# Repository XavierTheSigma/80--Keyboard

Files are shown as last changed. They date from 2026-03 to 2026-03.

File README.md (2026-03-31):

# Keyboard
My Keyboard is a standard 80% keyboard with an added Rotary Encoder for volume control.

I made this Keyboard for myself, And to learn. This was my first time using Chip on Board tech, so it was quite a challenge for me, but it helped me learn alot.

## Features:
- 80% Keyboard
- 87 Keys
- Rotary Encoder 
- Arrow Keys
- F Keys
- Chip On Board

## CAD Model:
I designed the Case to fit together with 3 pieces and 8 M2.5 screws. The 3 pieces are the Bottom of the case, The sides of the case (with a cutout for the USB-C) and the Top of the case, which includes the switch plate and the Top Frame. The Bottom and Sides are clearance holes and the screw threads into the top. The screw threads into 1.4mm of the top part and the screws are actually held .5mm higher than the bottom instead of flush.

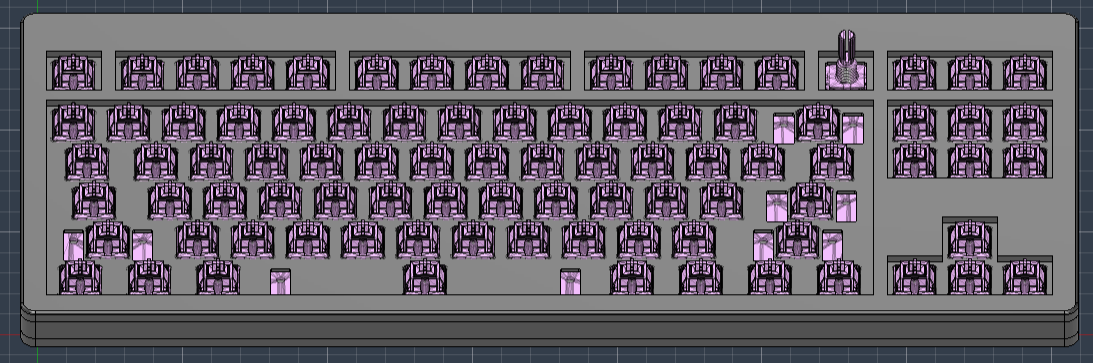
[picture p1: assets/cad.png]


## PCB:
I made my PCB in KiCad. This was my first time using CoB, Chip on Board, where instead of using a microcontroller, The RP2040 chip is directly on the board with all the other necessary components. I ended up reffereing to [RP2040 Datasheet](https://pip.raspberrypi.com/documents/RP-008371-DS-rp2040-datasheet.pdf) alot for this. 

Here is the Schematic, I spend alot of time figuring out how to get the whole CoB system working, but I think I did well.

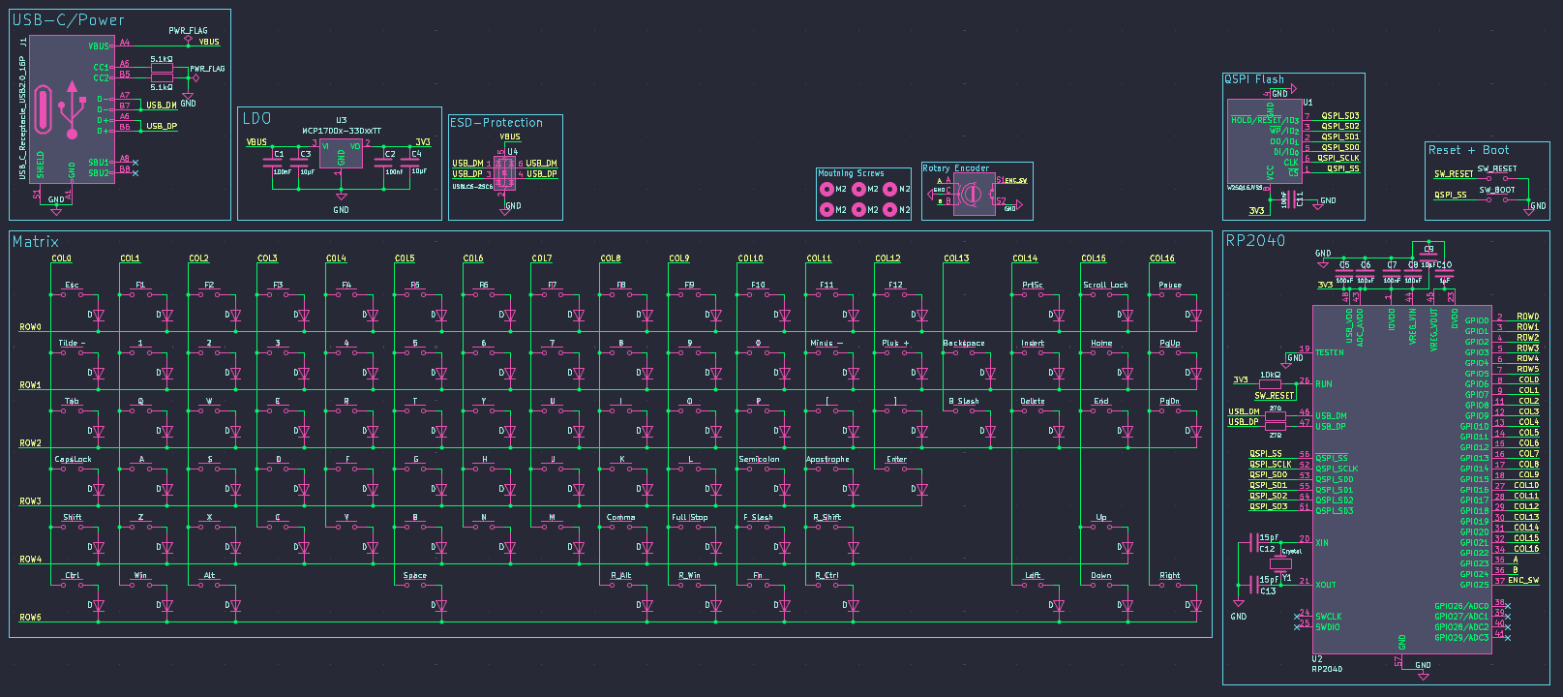
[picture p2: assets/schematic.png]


Here is the PCB, I think I was able to make it pretty Compact with the components, however I am still unsure about the USB-C port.

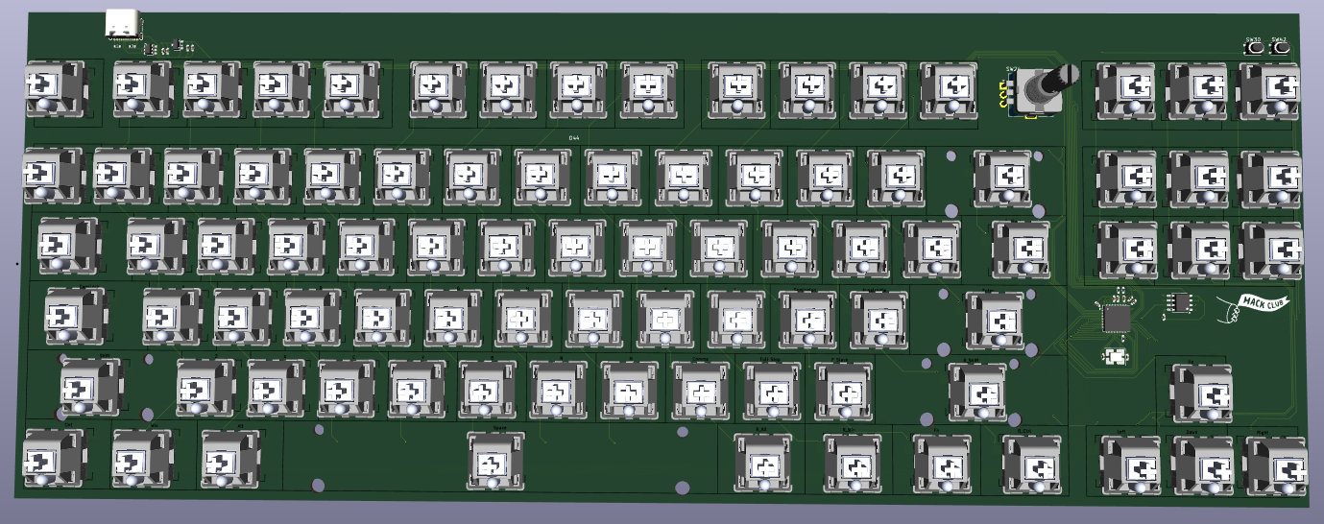
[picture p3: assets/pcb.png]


## Firmware:
I decided on [KMK](https://github.com/KMKfw/kmk_firmware) firmware for this keyboard, as it is quite easy to code and implement.

## BOM:
|Name |Purpose |Quantity|Total Cost (USD)|Link |Distributor|
|---|---|---|---|---|---|
|M2.5x12mm Screws |Hold the Case Together |100 |4.29 |https://www.aliexpress.com/item/1005006149650871.html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|Aliexpress |
|PCBA |Printed Circuit Board |2 |53.90 |https://cart.jlcpcb.com/shopcart/cart |JLCPCB |
|3x4mm SMD tactile switch|BOOT and RESET |100 |3.04 |https://www.aliexpress.com/item/1005005551946922.html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 |Aliexpress |
|Hotswap Sockets |For the switches to go into.|110 |6.78 |https://www.aliexpress.com/item/1005007232040760.html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 |Aliexpress |
|Rotary Encoder |Volume Control |2 |2.33 |https://www.aliexpress.com/item/1005009360298765.html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 |Aliexpress |
|Mechanical Switches |Register Keystrokes |90 |11.10 |https://www.aliexpress.com/item/1005010733013518.html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 |Aliexpress |
|Keycap Set |To press on |1 |12.61 |https://www.aliexpress.com/item/1005009316481772.html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 |Aliexpress |
|Stabilizers |Prevent Wobbling |1 |2.60 |https://www.aliexpress.com/item/1005007212869086.html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 |Aliexpress |
|1N5819 Diode (SMD) |Diodes for Matrix |100 |2.03 |https://www.aliexpress.com/item/1005010391501956.html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 |Aliexpress |
| | | | | | |

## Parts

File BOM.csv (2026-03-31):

Name | Purpose | Quantity | Total Cost (USD) | Link | Distributor
M2.5x12mm Screws | Hold the Case Together | 100 | 4.29 | https://www.aliexpress.com/item/1005006149650871.html?curPageLogUid=wg6dSTH9tu8G | Aliexpress
PCBA | Printed Circuit Board | 2 | 53.90 | https://cart.jlcpcb.com/shopcart/cart | JLCPCB
3x4mm SMD tactile switch | BOOT and RESET | 100 | 3.04 | https://www.aliexpress.com/item/1005005551946922.html?mp=1 | Aliexpress
Hotswap Sockets | For the switches to go into. | 110 | 6.78 | https://www.aliexpress.com/item/1005007232040760.html?mp=1 | Aliexpress
Rotary Encoder | Volume Control | 2 | 2.33 | https://www.aliexpress.com/item/1005009360298765.html?mp=1 | Aliexpress
Mechanical Switches | Register Keystrokes | 90 | 11.10 | https://www.aliexpress.com/item/1005010733013518.html?mp=1 | Aliexpress
Keycap Set | To press on | 1 | 12.61 | https://www.aliexpress.com/item/1005009316481772.html?mp=1 | Aliexpress
Stabilizers | Prevent Wobbling | 1 | 2.60 | https://www.aliexpress.com/item/1005007212869086.html?mp=1 | Aliexpress
1N5819 Diode (SMD) | Diodes for Matrix | 100 | 2.03 | https://www.aliexpress.com/item/1005010391501956.html?mp=1 | Aliexpress

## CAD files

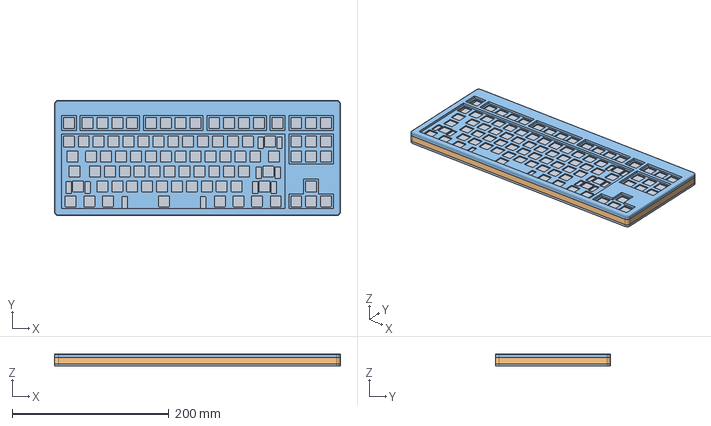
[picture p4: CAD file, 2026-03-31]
CAD/Keyboard.step
365.4 x 147.4 x 15.6 mm

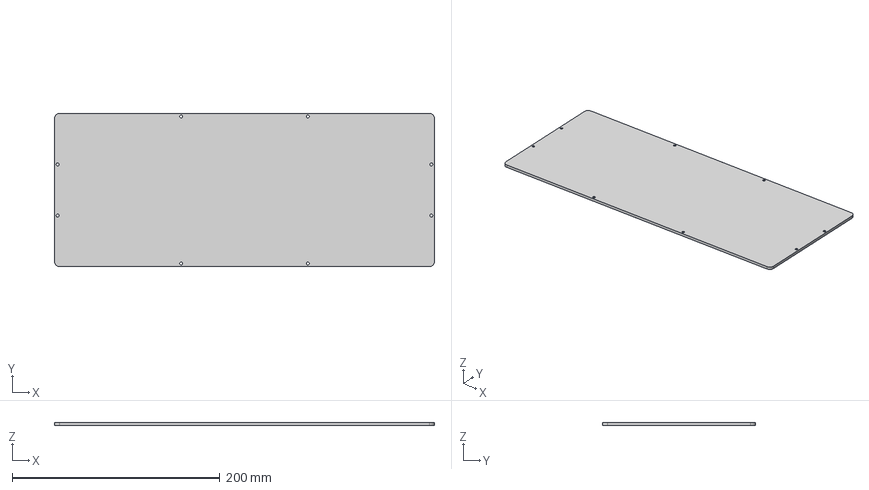
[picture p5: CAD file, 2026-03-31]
production/Bottom.step
365.4 x 147.4 x 3.00 mm

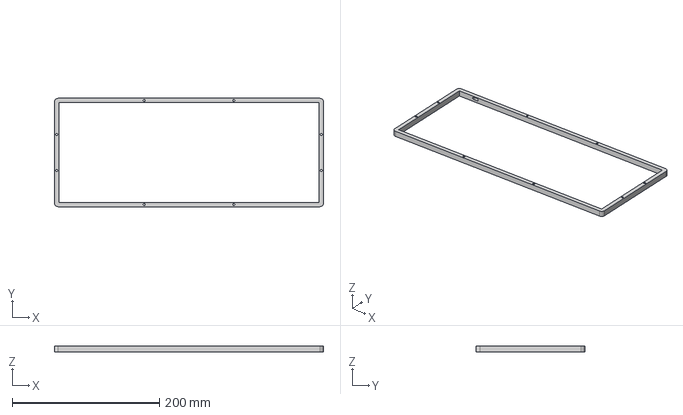
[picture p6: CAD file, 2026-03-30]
production/Sides.step
365.4 x 147.4 x 8.10 mm

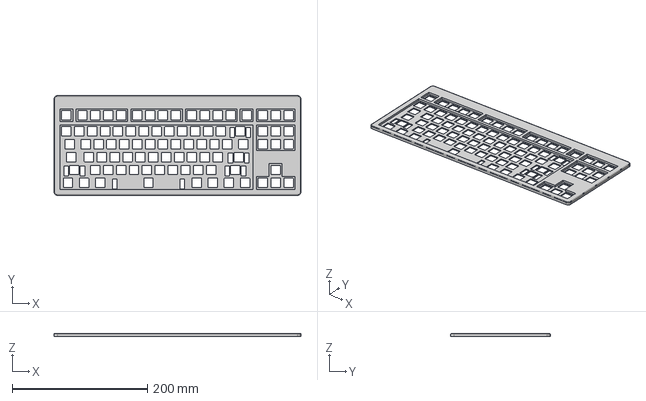
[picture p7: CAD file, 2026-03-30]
production/Top.step
365.4 x 147.4 x 4.50 mm

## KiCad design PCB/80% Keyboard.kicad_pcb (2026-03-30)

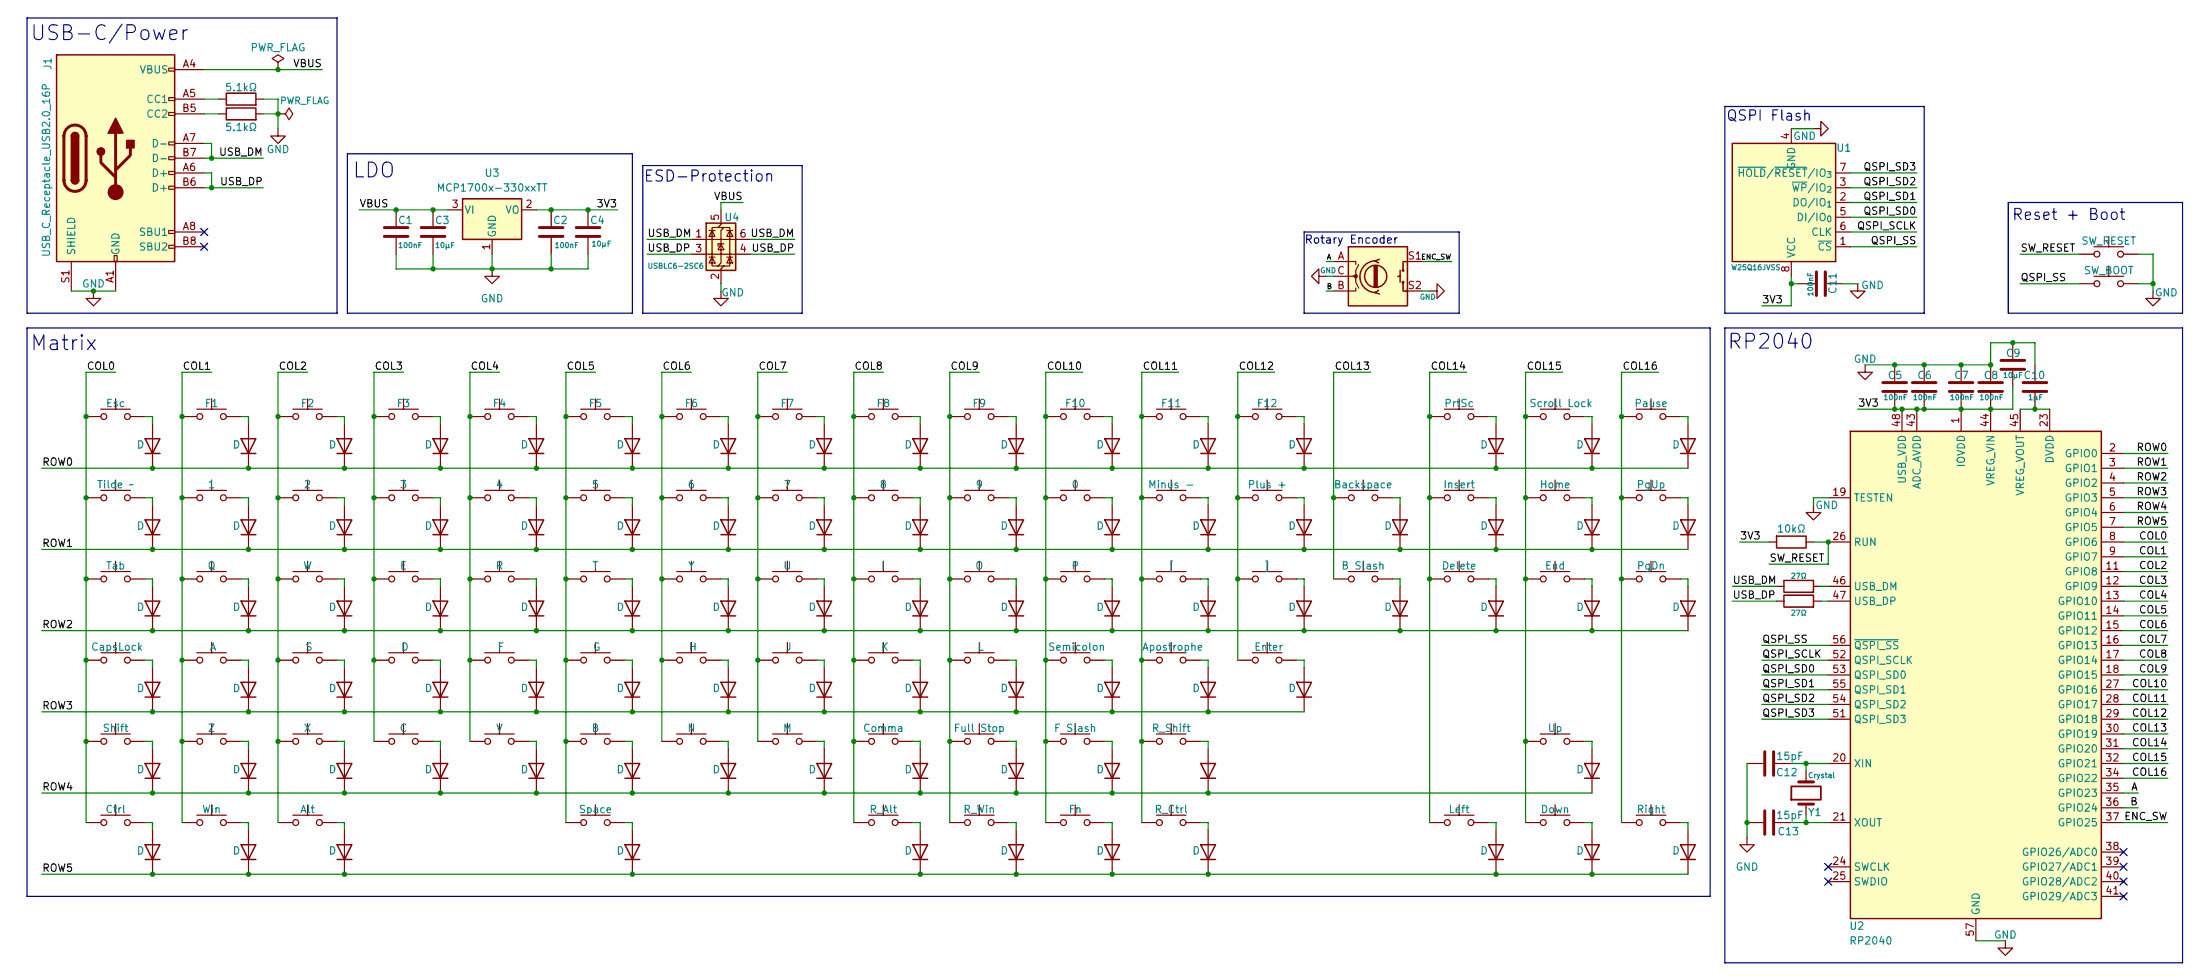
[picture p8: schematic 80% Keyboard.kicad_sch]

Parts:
C1, C2, C5, C6, C7, C8, C11: 100nF; C_0402_1005Metric_Pad0.74x0.62mm_HandSolder
C3, C4, C9: 10µF; C_0402_1005Metric_Pad0.74x0.62mm_HandSolder
C10: 1µF; C_0402_1005Metric_Pad0.74x0.62mm_HandSolder
C12, C13: 15pF; C_0402_1005Metric_Pad0.74x0.62mm_HandSolder
D1, D2, D3, D4, D5, D6, D7, D8, D9, D10, D11, D12, D13, D14, D15, D16, D17, D18, D19, D20, D21, D22, D23, D25, D26, D27, D28, D29, D31, D32, D33, D34, D35, D36, D37, D38, D39, D40, D41, D43, D44, D45, D46, D47, D49, D50, D51, D52, D53, D54, D55, D56, D57, D58, D59, D60, D61, D62, D63, D64, D65, D66, D67, D68, D69, D70, D71, D72, D73, D74, D75, D76, D80, D81, D85, D86, D87, D90, D91, D92, D93, D95, D96, D97, D98, D99, D102: D; D_SOD-123
J1: USB_C_Receptacle_USB2.0_16P; USB_C_Receptacle_GCT_USB4105-xx-A_16P_TopMnt_Horizontal
R1, R2: 5.1kΩ; R_0402_1005Metric_Pad0.72x0.64mm_HandSolder
R3: 10kΩ; R_0402_1005Metric_Pad0.72x0.64mm_HandSolder
R4, R5: 27Ω; R_0402_1005Metric_Pad0.72x0.64mm_HandSolder
SW1: Esc; MX-Hotswap-1U
SW2: Tilde ~; MX-Hotswap-1U
SW3: Tab; MX-Hotswap-1.5U
SW4: CapsLock; MX-Hotswap-1.75U
SW5: Shift; MX-Hotswap-2.25U
SW6: Ctrl; MX-Hotswap-1.25U
SW7: F1; MX-Hotswap-1U
SW8: 1; MX-Hotswap-1U
SW9: Q; MX-Hotswap-1U
SW10: A; MX-Hotswap-1U
SW11: Z; MX-Hotswap-1U
SW12: Win; MX-Hotswap-1.25U
SW13: F2; MX-Hotswap-1U
SW14: 2; MX-Hotswap-1U
SW15: W; MX-Hotswap-1U
SW16: S; MX-Hotswap-1U
SW17: X; MX-Hotswap-1U
SW18: Alt; MX-Hotswap-1.25U
SW19: F3; MX-Hotswap-1U
SW20: 3; MX-Hotswap-1U
SW21: E; MX-Hotswap-1U
SW22: D; MX-Hotswap-1U
SW23: C; MX-Hotswap-1U
SW24: RotaryEncoder; RotaryEncoder_Alps_EC11E-Switch_Vertical_H20mm
SW25: F4; MX-Hotswap-1U
SW26: 4; MX-Hotswap-1U
SW27: R; MX-Hotswap-1U
SW28: F; MX-Hotswap-1U
SW29: V; MX-Hotswap-1U
SW30: SW_BOOT; SW_Push_1P1T_NO_Vertical_Wuerth_434133025816
SW31: F5; MX-Hotswap-1U
SW32: 5; MX-Hotswap-1U
SW33: T; MX-Hotswap-1U
SW34: G; MX-Hotswap-1U
SW35: B; MX-Hotswap-1U
SW36: Space; MX-Hotswap-6.25U
SW37: F6; MX-Hotswap-1U
SW38: 6; MX-Hotswap-1U
SW39: Y; MX-Hotswap-1U
SW40: H; MX-Hotswap-1U
SW41: N; MX-Hotswap-1U
SW42: SW_RESET; SW_Push_1P1T_NO_Vertical_Wuerth_434133025816
SW43: F7; MX-Hotswap-1U
SW44: 7; MX-Hotswap-1U
SW45: U; MX-Hotswap-1U
SW46: J; MX-Hotswap-1U
SW47: M; MX-Hotswap-1U
SW49: F8; MX-Hotswap-1U
SW50: 8; MX-Hotswap-1U
SW51: I; MX-Hotswap-1U
SW52: K; MX-Hotswap-1U
SW53: Comma; MX-Hotswap-1U
SW54: R_Alt; MX-Hotswap-1.25U
SW55: F9; MX-Hotswap-1U
SW56: 9; MX-Hotswap-1U
SW57: O; MX-Hotswap-1U
SW58: L; MX-Hotswap-1U
SW59: Full Stop; MX-Hotswap-1U
SW60: R_Win; MX-Hotswap-1.25U
SW61: F10; MX-Hotswap-1U
SW62: 0; MX-Hotswap-1U
SW63: P; MX-Hotswap-1U
SW64: Semicolon; MX-Hotswap-1U
SW65: F Slash; MX-Hotswap-1U
SW66: Fn; MX-Hotswap-1.25U
SW67: F11; MX-Hotswap-1U
SW68: Minus -; MX-Hotswap-1U
SW69: [; MX-Hotswap-1U
SW70: Apostrophe; MX-Hotswap-1U
SW71: R_Shift; MX-Hotswap-2.75U
SW72: R_Ctrl; MX-Hotswap-1.25U
SW73: F12; MX-Hotswap-1U
SW74: Plus +; MX-Hotswap-1U
SW75: ]; MX-Hotswap-1U
SW76: Enter; MX-Hotswap-2.25U
SW80: Backspace; MX-Hotswap-2U
SW81: B Slash; MX-Hotswap-1.5U
SW85: PrtSc; MX-Hotswap-1U
SW86: Insert; MX-Hotswap-1U
SW87: Delete; MX-Hotswap-1U
SW90: Left; MX-Hotswap-1U
SW91: Scroll Lock; MX-Hotswap-1U
SW92: Home; MX-Hotswap-1U
SW93: End; MX-Hotswap-1U
SW95: Up; MX-Hotswap-1U
SW96: Down; MX-Hotswap-1U
SW97: Pause; MX-Hotswap-1U
SW98: PgUp; MX-Hotswap-1U
SW99: PgDn; MX-Hotswap-1U
SW102: Right; MX-Hotswap-1U
U1: W25Q16JVSS; SOIC-8_3.9x4.9mm_P1.27mm
U2: RP2040; QFN-56-1EP_7x7mm_P0.4mm_EP3.2x3.2mm
U3: MCP1700x-330xxTT; SOT-23
U4: USBLC6-2SC6; SOT-23-6
Y1: Crystal; Crystal_SMD_3225-4Pin_3.2x2.5mm_HandSoldering

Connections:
/3V3: C2.1, C4.1, C5.2, C6.2, C7.2, C8.2, C9.2, C11.2, R3.2, U1.8 (VCC), U2.1 (IOVDD), U2.10 (IOVDD), U2.22 (IOVDD), U2.33 (IOVDD), U2.42 (IOVDD), U2.43 (ADC_AVDD), U2.44 (VREG_VIN), U2.48 (USB_VDD), U2.49 (IOVDD), U3.2 (VO)
/A: SW24.A, U2.35 (GPIO23)
/B: SW24.B, U2.36 (GPIO24)
/COL0: SW1.1, SW2.1, SW3.1, SW4.1, SW5.1, SW6.1, U2.8 (GPIO6)
/COL1: SW7.1, SW8.1, SW9.1, SW10.1, SW11.1, SW12.1, U2.9 (GPIO7)
/COL2: SW13.1, SW14.1, SW15.1, SW16.1, SW17.1, SW18.1, U2.11 (GPIO8)
/COL3: SW19.1, SW20.1, SW21.1, SW22.1, SW23.1, U2.12 (GPIO9)
/COL4: SW25.1, SW26.1, SW27.1, SW28.1, SW29.1, U2.13 (GPIO10)
/COL5: SW31.1, SW32.1, SW33.1, SW34.1, SW35.1, SW36.1, U2.14 (GPIO11)
/COL6: SW37.1, SW38.1, SW39.1, SW40.1, SW41.1, U2.15 (GPIO12)
/COL7: SW43.1, SW44.1, SW45.1, SW46.1, SW47.1, U2.16 (GPIO13)
/COL8: SW49.1, SW50.1, SW51.1, SW52.1, SW53.1, SW54.1, U2.17 (GPIO14)
/COL9: SW55.1, SW56.1, SW57.1, SW58.1, SW59.1, SW60.1, U2.18 (GPIO15)
/COL10: SW61.1, SW62.1, SW63.1, SW64.1, SW65.1, SW66.1, U2.27 (GPIO16)
/COL11: SW67.1, SW68.1, SW69.1, SW70.1, SW71.1, SW72.1, U2.28 (GPIO17)
/COL12: SW73.1, SW74.1, SW75.1, SW76.1, U2.29 (GPIO18)
/COL13: SW80.1, SW81.1, U2.30 (GPIO19)
/COL14: SW85.1, SW86.1, SW87.1, SW90.1, U2.31 (GPIO20)
/COL15: SW91.1, SW92.1, SW93.1, SW95.1, SW96.1, U2.32 (GPIO21)
/COL16: SW97.1, SW98.1, SW99.1, SW102.1, U2.34 (GPIO22)
/ENC_SW: SW24.S1, U2.37 (GPIO25)
/QSPI_SCLK: U1.6 (CLK), U2.52 (QSPI_SCLK)
/QSPI_SD0: U1.5 (DI/IO_{0}), U2.53 (QSPI_SD0)
/QSPI_SD1: U1.2 (DO/IO_{1}), U2.55 (QSPI_SD1)
/QSPI_SD2: U1.3 (~WP/IO_{2}), U2.54 (QSPI_SD2)
/QSPI_SD3: U1.7 (~HOLD/~RESET/IO_{3}), U2.51 (QSPI_SD3)
/QSPI_SS: SW30.1, U1.1 (~CS), U2.56 (~QSPI_SS)
/ROW0: D1.1 (K), D7.1 (K), D13.1 (K), D19.1 (K), D25.1 (K), D31.1 (K), D37.1 (K), D43.1 (K), D49.1 (K), D55.1 (K), D61.1 (K), D67.1 (K), D73.1 (K), D85.1 (K), D91.1 (K), D97.1 (K), U2.2 (GPIO0)
/ROW1: D2.1 (K), D8.1 (K), D14.1 (K), D20.1 (K), D26.1 (K), D32.1 (K), D38.1 (K), D44.1 (K), D50.1 (K), D56.1 (K), D62.1 (K), D68.1 (K), D74.1 (K), D80.1 (K), D86.1 (K), D92.1 (K), D98.1 (K), U2.3 (GPIO1)
/ROW2: D3.1 (K), D9.1 (K), D15.1 (K), D21.1 (K), D27.1 (K), D33.1 (K), D39.1 (K), D45.1 (K), D51.1 (K), D57.1 (K), D63.1 (K), D69.1 (K), D75.1 (K), D81.1 (K), D87.1 (K), D93.1 (K), D99.1 (K), U2.4 (GPIO2)
/ROW3: D4.1 (K), D10.1 (K), D16.1 (K), D22.1 (K), D28.1 (K), D34.1 (K), D40.1 (K), D46.1 (K), D52.1 (K), D58.1 (K), D64.1 (K), D70.1 (K), D76.1 (K), U2.5 (GPIO3)
/ROW4: D5.1 (K), D11.1 (K), D17.1 (K), D23.1 (K), D29.1 (K), D35.1 (K), D41.1 (K), D47.1 (K), D53.1 (K), D59.1 (K), D65.1 (K), D71.1 (K), D95.1 (K), U2.6 (GPIO4)
/ROW5: D6.1 (K), D12.1 (K), D18.1 (K), D36.1 (K), D54.1 (K), D60.1 (K), D66.1 (K), D72.1 (K), D90.1 (K), D96.1 (K), D102.1 (K), U2.7 (GPIO5)
/SW_RESET: R3.1, SW42.1, U2.26 (RUN)
/USB_DM: J1.A7 (D-), J1.B7 (D-), R4.1, U4.1 (I/O1), U4.6 (I/O1)
/USB_DP: J1.A6 (D+), J1.B6 (D+), R5.1, U4.3 (I/O2), U4.4 (I/O2)
/VBUS: C1.1, C3.1, J1.A4 (VBUS), J1.A9 (VBUS), J1.B4 (VBUS), J1.B9 (VBUS), U3.3 (VI), U4.5 (VBUS)
GND: C1.2, C2.2, C3.2, C4.2, C5.1, C6.1, C7.1, C8.1, C9.1, C10.1, C11.1, C12.1, C13.1, J1.A1 (GND), J1.A12 (GND), J1.B1 (GND), J1.B12 (GND), J1.S1 (SHIELD), R1.2, R2.2, SW24.C, SW24.S2, SW30.2, SW42.2, U1.4 (GND), U2.19 (TESTEN), U2.57 (GND), U3.1 (GND), U4.2 (GND), Y1.3, Y1.4
unnamed: D1.2 (A), SW1.2
unnamed: D2.2 (A), SW2.2
unnamed: D3.2 (A), SW3.2
unnamed: D4.2 (A), SW4.2
unnamed: D5.2 (A), SW5.2
unnamed: D6.2 (A), SW6.2
unnamed: D7.2 (A), SW7.2
unnamed: D8.2 (A), SW8.2
unnamed: D9.2 (A), SW9.2
unnamed: D10.2 (A), SW10.2
unnamed: D11.2 (A), SW11.2
unnamed: D12.2 (A), SW12.2
unnamed: D13.2 (A), SW13.2
unnamed: D14.2 (A), SW14.2
unnamed: D15.2 (A), SW15.2
unnamed: D16.2 (A), SW16.2
unnamed: D17.2 (A), SW17.2
unnamed: D18.2 (A), SW18.2
unnamed: D19.2 (A), SW19.2
unnamed: D20.2 (A), SW20.2
unnamed: D21.2 (A), SW21.2
unnamed: D22.2 (A), SW22.2
unnamed: D23.2 (A), SW23.2
unnamed: D25.2 (A), SW25.2
unnamed: D26.2 (A), SW26.2
unnamed: D27.2 (A), SW27.2
unnamed: D28.2 (A), SW28.2
unnamed: D29.2 (A), SW29.2
unnamed: D31.2 (A), SW31.2
unnamed: D32.2 (A), SW32.2
unnamed: D33.2 (A), SW33.2
unnamed: D34.2 (A), SW34.2
unnamed: D35.2 (A), SW35.2
unnamed: D36.2 (A), SW36.2
unnamed: D37.2 (A), SW37.2
unnamed: D38.2 (A), SW38.2
unnamed: D39.2 (A), SW39.2
unnamed: D40.2 (A), SW40.2
unnamed: D41.2 (A), SW41.2
unnamed: D43.2 (A), SW43.2
unnamed: D44.2 (A), SW44.2
unnamed: D45.2 (A), SW45.2
unnamed: D46.2 (A), SW46.2
unnamed: D47.2 (A), SW47.2
unnamed: D49.2 (A), SW49.2
unnamed: D50.2 (A), SW50.2
unnamed: D51.2 (A), SW51.2
unnamed: D52.2 (A), SW52.2
unnamed: D53.2 (A), SW53.2
unnamed: D54.2 (A), SW54.2
unnamed: D55.2 (A), SW55.2
unnamed: D56.2 (A), SW56.2
unnamed: D57.2 (A), SW57.2
unnamed: D58.2 (A), SW58.2
unnamed: D59.2 (A), SW59.2
unnamed: D60.2 (A), SW60.2
unnamed: D61.2 (A), SW61.2
unnamed: D62.2 (A), SW62.2
unnamed: D63.2 (A), SW63.2
unnamed: D64.2 (A), SW64.2
unnamed: D65.2 (A), SW65.2
unnamed: D66.2 (A), SW66.2
unnamed: D67.2 (A), SW67.2
unnamed: D68.2 (A), SW68.2
unnamed: D69.2 (A), SW69.2
unnamed: D70.2 (A), SW70.2
unnamed: D71.2 (A), SW71.2
unnamed: D72.2 (A), SW72.2
unnamed: D73.2 (A), SW73.2
unnamed: D74.2 (A), SW74.2
unnamed: D75.2 (A), SW75.2
unnamed: D76.2 (A), SW76.2
unnamed: D80.2 (A), SW80.2
unnamed: D81.2 (A), SW81.2
unnamed: D85.2 (A), SW85.2
unnamed: D86.2 (A), SW86.2
unnamed: D87.2 (A), SW87.2
unnamed: D90.2 (A), SW90.2
unnamed: D91.2 (A), SW91.2
unnamed: D92.2 (A), SW92.2
unnamed: D93.2 (A), SW93.2
unnamed: D95.2 (A), SW95.2
unnamed: D96.2 (A), SW96.2
unnamed: D97.2 (A), SW97.2
unnamed: D98.2 (A), SW98.2
unnamed: D99.2 (A), SW99.2
unnamed: D102.2 (A), SW102.2
unnamed: J1.A5 (CC1), R1.1
unnamed: J1.B5 (CC2), R2.1
unnamed: R4.2, U2.46 (USB_DM)
unnamed: R5.2, U2.47 (USB_DP)
unnamed: C10.2, U2.23 (DVDD), U2.45 (VREG_VOUT), U2.50 (DVDD)
unnamed: C12.2, U2.20 (XIN), Y1.2
unnamed: C13.2, U2.21 (XOUT), Y1.1

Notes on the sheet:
Reset + Boot
Rotary Encoder
RP2040
ESD-Protection
Matrix
USB-C/Power
QSPI Flash
LDO

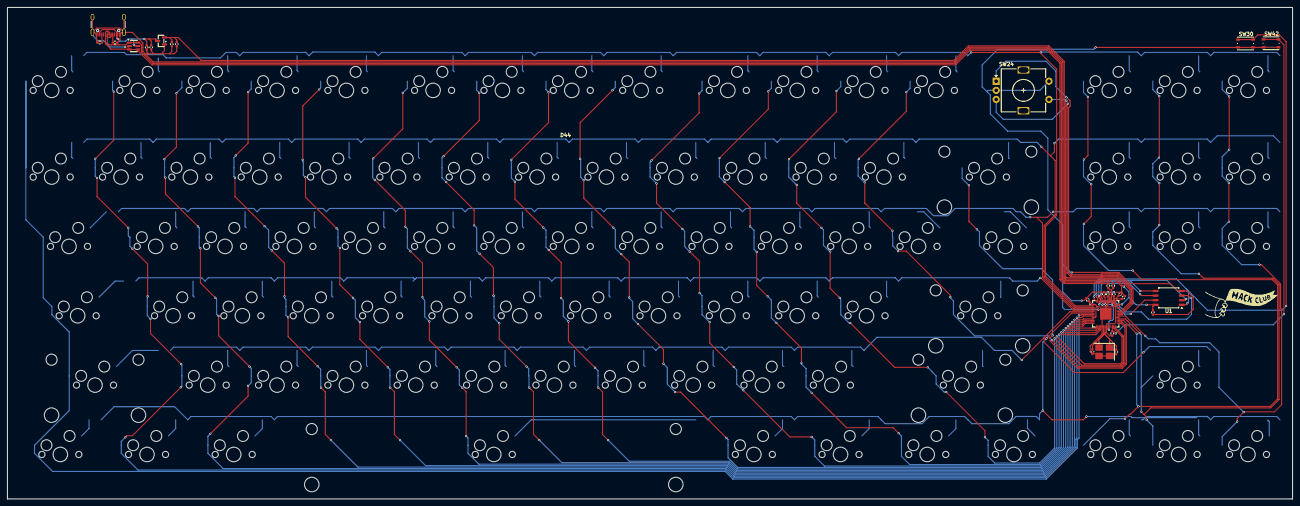
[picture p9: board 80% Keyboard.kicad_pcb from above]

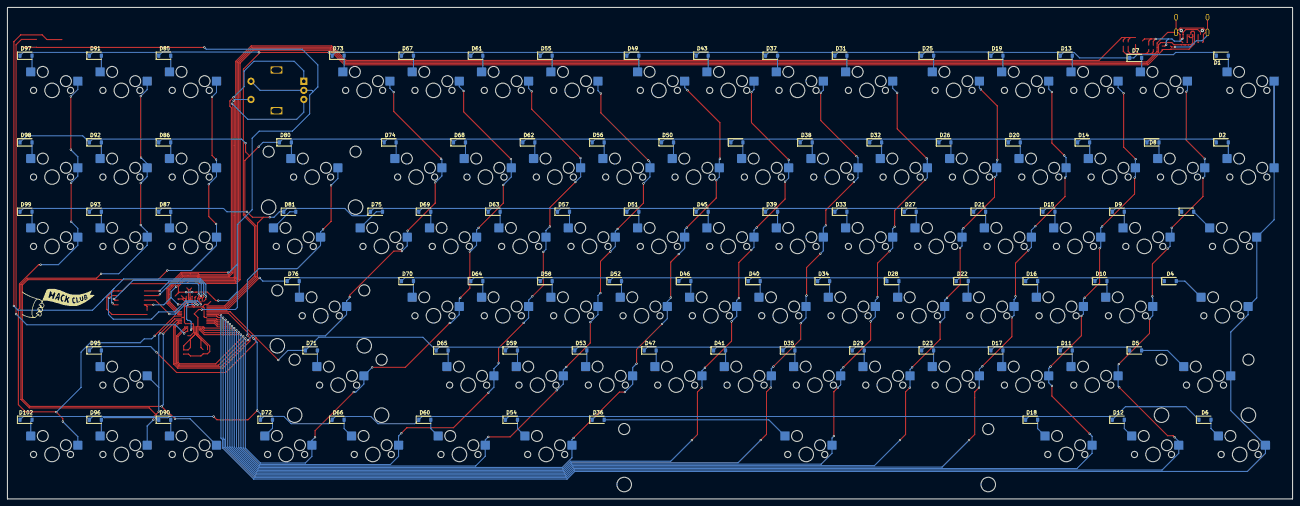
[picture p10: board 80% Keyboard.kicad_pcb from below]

Board: 2 copper layers, 353.0 x 135.0 mm, 201 parts (174 on the bottom side), 132 nets.

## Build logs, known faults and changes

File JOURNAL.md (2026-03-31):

<!--
  This journal is auto generated by Stasis.
-->

# 3/31/2026 2 AM - BOM Parts + PCBA

_Time spent: 3h_

I Spent Probably 2 hours today making sure that the JLCPCB PCBA would go well, and all the parts are good. I Also found all of the other parts that I would need on Aliexpress and added them to my BOM.

Here is my PCBA. I am worried that I wont be able to recieve enough funding for this project because the PCB + Shipping alone is about USD$90. But I am hoping that I can qualify for Tier 4.


I spent a bit of time on Aliexpress to get all my other parts for cheap to keep my cost down. 


Once I had actually found all my parts and finished the PCBA I put everthing into the BOM for the project.


I then Uploaded the Bom into my Github and added it in table format to my README.MD using a [CSV to MarkDown Converter](https://www.convertcsv.com/csv-to-markdown.htm).


<!--
![image](https://stasis.hackclub-assets.com/images/1774924442148-j057ns.png)
![image](https://stasis.hackclub-assets.com/images/1774924589427-3am242.png)
![image](https://stasis.hackclub-assets.com/images/1774924633874-vl8jb6.png)
![image](https://stasis.hackclub-assets.com/images/1774924812382-vsyk9g.png)
-->

# 3/30/2026 12 PM - Finishing Touches on Case + Small Change to PCB

_Time spent: 3.33h_

I Finished up the finishing touches of the case. 

I added 1mm to the bottom, then I countersunk it by 1.6mm so that the screw does not hold up the case.



I Also Curved the Corners on the sides + on the top.



Redid the Top Frame, its alot better and finished now, i spaced them by 19.05mm.




I added the USB-C Port Hole, added .2mm clearance to the hole, and rounded it a bit.




Small changes i added to the pcb, i changed the crystal footprint to SOIC-8_5.3x5.3mm_P1.27mm so that it was easier to find a part for PCBA.



And I Did the PCBA Parts



<!--
![image](https://stasis.hackclub-assets.com/images/1774873519261-i5l9yw.png)
![image](https://stasis.hackclub-assets.com/images/1774873584659-3a6lsl.png)
![image](https://stasis.hackclub-assets.com/images/1774873631792-j4rbmc.png)
![image](https://stasis.hackclub-assets.com/images/1774873649982-gqvq0o.png)
![image](https://stasis.hackclub-assets.com/images/1774873767532-huzk3p.png)
![image](https://stasis.hackclub-assets.com/images/1774873783523-uze05v.png)
![image](https://stasis.hackclub-assets.com/images/1774873861177-gv2xhl.png)
![image](https://stasis.hackclub-assets.com/images/1774873806209-wbfza1.png)
-->

# 3/30/2026 2 AM - Case

_Time spent: 3.5h_

# Case
I Finally started work on the Case for the keyboard. I did research and I decided to self threaded the holes using the screws. I chose this option because I wanted to stick to 6mm wide sides and heat set inserts would not work with that.

I've done the Basic Shell with the Bottom, Sides, And Plate.

## Bottom
With the Bottom I used 2.9mm holes as clearance for the M2.5 screws. And I added .2mm of extra distance in the center where the pcb rests.



## Sides
For the Sides I decided on 6mm Thickness, Not too Thick, and its enough for the Plastic. These also use 2.9mm Clearance holes.



## Top
For the Plate I used [ai03 Plate Generator](https://kbplate.ai03.com/) to generate it, then I manually added the hole for the Rotary encoder.


The plate uses 2.2mm holes so that the M2.5 screws thread into it. For now I added 3mm on the sides on top of the Plate but that may change.

### KLE
Here is the KLE data I used for the plate:

`[{a:7},"",{x:0.25},"","","","",{x:0.25},"","","","",{x:0.25},"","","","",{x:1.5},"","",""],[{y:0.25},"","","","","","","","","","","","","",{w:2},"",{x:0.25},"","",""],[{w:1.5},"","","","","","","","","","","","","",{w:1.5},"",{x:0.25},"","",""],[{w:1.75},"","","","","","","","","","","","",{w:2.25},""],[{w:2.25},"","","","","","","","","","","",{w:2.75},"",{x:1.25},""],[{w:1.25},"",{w:1.25},"",{w:1.25},"",{w:6.25},"",{w:1.25},"",{w:1.25},"",{w:1.25},"",{w:1.25},"",{x:0.25},"","",""]`

<!-- 
![image](https://stasis.hackclub-assets.com/images/1774834336654-hpsc4g.png)
![image](https://stasis.hackclub-assets.com/images/1774834338463-gsktvc.png)
![image](https://stasis.hackclub-assets.com/images/1774834372655-iks0x3.png)
![image](https://stasis.hackclub-assets.com/images/1774836087596-solkto.png)
![image](https://stasis.hackclub-assets.com/images/1774836090680-mlahpb.png)
-->

# 3/24/2026 4 AM - Upgraded The PCB + Research

_Time spent: 5h_

I Redid some parts of the PCB, making it a bit more compact. I also slightly changed up the USB-C Receptacle.


I Also did more reseach on the Sandwich Mount Case and I think I finally figured out the measurements. I think this is correct for my Build:

---Top--- 3mm

---Plate--- 1.5mm

---Gap--- 3.5mm

---PCB--- 1.6mm

---Gap--- 3mm

---Bottom--- 3mm

---Sides--- 6mm

Then I think I will use M3 Screws. Im planning to get my case CNC manufactured. I Spent way too much time researching for these measurments as i couldnt find much information about them.

Edit:
ive done a bit more research, i cannot get it made with CNC, I will 3D print the case myself, I will use M2.5 screws and heat set inserts to hold it together. I will Print the Bottom and Sides of the Case together and then I will print the plate and top frame together. The case has probably been the hardest part of this project so far and I havent even started designing it :

<!-- 
![image](https://stasis.hackclub-assets.com/images/1774327407927-80l9tm.png)
![image](https://stasis.hackclub-assets.com/images/1774327421392-co99j7.png)
-->

# 3/23/2026 11 AM - Fixed a Big Mistake

_Time spent: 3.5h_

I was adding 3D models to the footprints, so that i could see what it would look like.then i realised that all of my hotswap sockets, were on the wrong side.

I had to go through each and every individual socket, and flip it to the other side. Then I also had to redo alot of the routing.




Ive fixed it now, It was quite tedious and ive learned from my mistakes.
I also did some research on the sandwich mount, but I havent started on the actual Case yet. While researching The Sandwich mount, I realised that I do not need the Mounting holes, as the pins of the switches hold it up.



<!-- 
![image](https://stasis.hackclub-assets.com/images/1774265803379-yuubdf.png)
![image](https://stasis.hackclub-assets.com/images/1774265810011-gd4ecn.png)
![image](https://stasis.hackclub-assets.com/images/1774265885290-zzi3t1.png)
-->

# 3/23/2026 3 AM - Mounting Screws + Art

_Time spent: 0.33h_

Today I added the M2 Mounting Screws to the Schematic and PCB. I added 6 Mounting Screws in Total, which I think should be enough to hold the PCB securely.

Schematic:



PCB:



I also added the Hack Club flag on both sides and, I added my Name!




<!-- 
![image](https://stasis.hackclub-assets.com/images/1774237415648-qjryj0.png)
![image](https://stasis.hackclub-assets.com/images/1774237438997-cd1f8k.png)
![image](https://stasis.hackclub-assets.com/images/1774237479496-7ro8k2.png)
![image](https://stasis.hackclub-assets.com/images/1774237488088-f9fcug.png)
-->

# 3/23/2026 1 AM - The Entire PCB

_Time spent: 6.25h_

On Friday, after school, I spent 6 hours putting together the PCB. That includes placing all the footprints, and routing everything together. I also used lapse for the first time to record a timelapse of me doing this!

I did not know about whether using plugins to place the keys were allowed so I manually placed each and every single one and their respective diode in the top left of that key. With routing the main RP2040 chip, I did struggle a bit, it took a lot of trial and error, but I eventually figured it out. To help me with the main Chip I looked at the main RP2040 documentation and at the Devboard Guide as it was similar in some aspects.
https://pip.raspberrypi.com/documents/RP-008371-DS-rp2040-datasheet.pdf and https://stasis.hackclub.com/starter-projects/devboard

For the USB-C receptacle I think I did pretty good routing it together, however I'm still not sure on the placement and it is subject to change.


Here is my main Chip including the Flash chip and the Crystal:


In my next log I might add the Mounting holes and some artwork/text to the silkscreen, just to make it unique.

<!-- 
![image](https://stasis.hackclub-assets.com/images/1774228326179-9eu2v3.png)
![image](https://stasis.hackclub-assets.com/images/1774228469262-k4y9tb.png)
![image](https://stasis.hackclub-assets.com/images/1774228534015-zzz2yu.png)
-->

# 3/19/2026 11 AM - Added The RP2040 COB

_Time spent: 6.25h_

# RP2040

I spent a good lot of time creating the setup for the COB, adding the main RP2040 which has enough pins for my matrix setup and is compatiple with QMK firmware. It isnt just finished yet. I added:

USB-C_Receptacle
---


This is the main port that powers the keyboard.

LDO regulator
--


ESD Protection
--


The Rotary Encoder
--


This will be used to adjust volume or completely mute.

QSPI Flash
--


Reset and Boot Buttons
--


And the main RP2040
--


I spent quite a lot of time on this and going through the RP2040 Documents and the Pico schematics for reference, but I think I did quite well?

Im sorry I couldn't write more about my experience for this part but I spent a lot of time racking my head trying to figure this stuff out.

<!-- 
![image](https://stasis.hackclub-assets.com/images/1773920810508-c3bn2a.png)
![image](https://stasis.hackclub-assets.com/images/1773920879636-oxp11n.png)
![image](https://stasis.hackclub-assets.com/images/1773920909806-n3y93t.png)
![image](https://stasis.hackclub-assets.com/images/1773920934529-vi7pwo.png)
![image](https://stasis.hackclub-assets.com/images/1773921006453-8jicus.png)
![image](https://stasis.hackclub-assets.com/images/1773921026704-4ywz2z.png)
![image](https://stasis.hackclub-assets.com/images/1773921051762-q0rn1l.png)
-->

# 3/19/2026 6 AM - I Figured Out the Design + Start of Schematic

_Time spent: 2.5h_

The Planning
-

I First decided what I wanted this project to be. I had a clear image in mind, to make a keyboard with everything I would ever need, with the following features:
- 80% Layout
- Volume Knob
- COB PCB Technology (First Time)
- Hotswappable
- Gasket Mount

I have planned out and made the start of the schematic for the key matrix. I used this 80% keyboard reference to help me understand and plan it.

The blue lines are the rows and the red lines are the columns.

Once I had the matrix drafted out, I put it into KiCad. I laid out the Rows and the Columns, then I placed the switches in the correct positions (With the Diodes).

I know that I maybe could've optimised it to use less pins, but as of now I have no reason to minimize the amount of used pins and it would make the layout a lot harder to read.

Previously when I have made a matrix, I have edited the value of each switch to its respective key. e.g. SW -> Esc. But this time I made an embarassing mistake and edited the Reference instead of the value, I then had to go through all of the switches and correct my mistake.

<!-- 
![image](https://stasis.hackclub-assets.com/images/1773919742843-iutj73.png)
![image](https://stasis.hackclub-assets.com/images/1773920029648-xc9upg.png)
-->

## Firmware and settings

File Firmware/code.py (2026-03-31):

from kb import keyboard, encoder_handler
from kmk.keys import KC
from kmk.modules.encoder import EncoderHandler

keyboard.keymap = [
     # Layer 0
    [
        # ROW0
        KC.ESC, KC.F1, KC.F2, KC.F3, KC.F4, KC.F5, KC.F6, KC.F7, KC.F8, KC.F9, KC.F10, KC.F11, KC.F12, KC.TRNS, KC.PSCR, KC.SLCK, KC.PAUS,
        # ROW1
        KC.GRAVE, KC.N1, KC.N2, KC.N3, KC.N4, KC.N5, KC.N6, KC.N7, KC.N8, KC.N9, KC.N0, KC.MINUS, KC.EQUAL, KC.BSPC, KC.INS, KC.HOME, KC.PGUP,
        # ROW2
        KC.TAB, KC.Q, KC.W, KC.E, KC.R, KC.T, KC.Y, KC.U, KC.I, KC.O, KC.P, KC.LBRACKET, KC.RBRACKET, KC.BSLS, KC.DEL, KC.END, KC.PGDN,
        # ROW3
        KC.CAPS, KC.A, KC.S, KC.D, KC.F, KC.G, KC.H, KC.J, KC.K, KC.L, KC.SCLN, KC.QUOT, KC.ENT, KC.TRNS, KC.TRNS, KC.TRNS, KC.TRNS,
        # ROW4
        KC.LSFT, KC.Z, KC.X, KC.C, KC.V, KC.B, KC.N, KC.M, KC.COMM, KC.DOT, KC.SLSH, KC.RSFT, KC.TRNS, KC.TRNS, KC.TRNS, KC.UP, KC.TRNS,
        # ROW5
        KC.LCTL, KC.LGUI, KC.LALT, KC.TRNS, KC.TRNS, KC.SPC, KC.TRNS, KC.TRNS, KC.RALT, KC.RGUI, KC.FN, KC.RCTL, KC.TRNS, KC.TRNS, KC.LEFT, KC.DOWN, KC.RIGHT,
    ]
]

encoder_handler.map = [
    ((KC.VOLD, KC.VOLU, KC.MUTE),), # Layer 0
]

if __name__ == '__main__':
    keyboard.go()

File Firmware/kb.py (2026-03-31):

import board
from kmk.kmk_keyboard import KMKKeyboard
from kmk.scanners.keypad import MatrixScanner
from kmk.modules.encoder import EncoderHandler
from kmk.matrix import DiodeOrientation

keyboard = KMKKeyboard()

keyboard.matrix = MatrixScanner(
    column_pins=(
        board.GP6,
        board.GP7,
        board.GP8,
        board.GP9,
        board.GP10,
        board.GP11,
        board.GP12,
        board.GP13,
        board.GP14,
        board.GP15,
        board.GP16,
        board.GP17,
        board.GP18,
        board.GP19,
        board.GP20,
        board.GP21,
        board.GP22,
    ),
    row_pins=(
        board.GP0,
        board.GP1,
        board.GP2,
        board.GP3,
        board.GP4,
        board.GP5,
    ),
    diode_orientation=DiodeOrientation.COL2ROW,
)

encoder_handler = EncoderHandler()
encoder_handler.pins = (
    (board.GP23, board.GP24, board.GP25, False),
)

keyboard.modules.append (encoder_handler)

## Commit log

2026-03-19 Structure + PCB
    [80% Keyboard.kicad_pcb, 80% Keyboard.kicad_sch, BOM.csv]
2026-03-19 Added Crystal
    [80% Keyboard.kicad_sch]
2026-03-23 Entire PCB + Updated Journal.MD
    [80% Keyboard.kicad_pcb, 80% Keyboard.kicad_sch]
2026-03-23 Artwork + Name + Journal
    [80% Keyboard.kicad_pcb, 80% Keyboard.kicad_sch]
2026-03-30 All of CAD Case + Clean Up of PCB Files
    [80% Keyboard.kicad_pcb, Bottom.step, Keyboard.step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]
2026-03-30 Information Proto
    [BOM.csv]
2026-03-30 Added PCB img
2026-03-30 Bom Stuff
    [80% Keyboard.kicad_pcb, 80% Keyboard.kicad_sch, BOM.csv]
2026-03-31 All of BOM pretty much
    [BOM.csv]
2026-03-31 Keyboard Bottom Adjustments
    [Bottom.step, Keyboard.step]
